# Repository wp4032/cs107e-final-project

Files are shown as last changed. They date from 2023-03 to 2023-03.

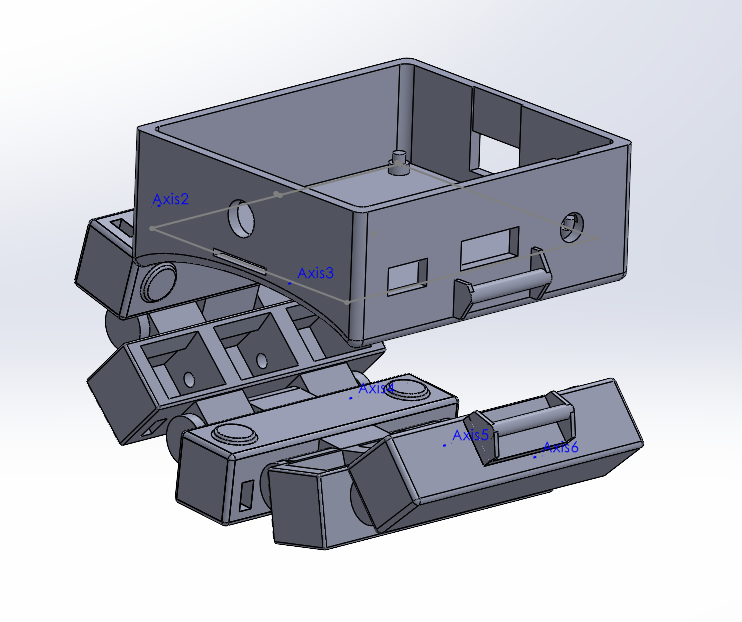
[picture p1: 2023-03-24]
doc/F - PI CAD 1.png

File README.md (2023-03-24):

## Project title
DREAMS DON'T DIE -- MOONWALKER
An EMG-based Brain Machine Interface to Control The World

## Team members
Willian Pan

## Project description
Our nerves communicate with all of our body through send electrical and chemical signals through neurons to the 
desired muscle. It is possible to read these signals from putting electrodes on the skin to detect when certain muscles
fire and relax. Here at DREAMS DON'T DIE Inc., we have designed a wristband that detects these electrical muscle signals
to determine when we have activated a muscle in our hand. As well, using an accelerometer, we can determine the position
of our hand in order to interact with the digital world through this wristband. The project is to build this device and have
it integrate with drawing on the screen like a simple Paint program.

## Instructions
To start the program, run `make` in terminal and then copy the `moonwalker.bin` file to the Raspberry Pi memory card and rename the file
to `kernel.img` while keeping the `bootcode.bin` and `start.elf`. 

Connect a USB A connection the Pi to power the device and also an HDMI cable to output the screen on any desired screen

## Member contribution
William built and designed the physical mechanical parts, circuitry, and software of the device

## References
This project was influenced by CTRL Labs, a company acquired by Meta, that is a wristband with EMG sensors used to interface 
in virtual reality. The device can differentiate when someone uses their fingers in VR, allowing better interaction with virtual 
reality.

The following project also cited several algorithms found online (they are also sprinkled throughout the source code in comments):
- Device Patent: https://patentimages.storage.googleapis.com/3c/5a/7b/39b871805f7eaa/US11045137.pdf
- EMG Circuit: https://www.instructables.com/Muscle-EMG-Sensor-for-a-Microcontroller/
- Tracking arm using accelerometer: https://synrg.csl.illinois.edu/papers/ArmTrak_Mobisys.pdf
- Accelerometer and gyroscope sensor fusion: https://github.com/seanboe/SimpleFusion/blob/master/src/simpleFusion.cpp
- Accelerometer, I2C, LSM6DS33: from CS 107E
- Square root function: https://www.codeproject.com/Articles/570700/SquareplusRootplusalgorithmplusforplusC
- Xiaolin Wu's line drawing algorithm: https://en.wikipedia.org/wiki/Xiaolin_Wu%27s_line_algorithm
- Bresenham circle drawing algorithm: https://www.gatevidyalay.com/bresenham-circle-drawing-algorithm/
- Circle drawing octant: https://www.cs.helsinki.fi/group/goa/mallinnus/ympyrat/ymp1.html

## Self-evaluation
I say that I am pretty proud of building something from the mechanical parts to the electrical parts to the software. It really broadens
my horizons of what full stack means and why hardware is hard. I was able to execute on half of my plan as I was able to get a commercial EMG circuit
board from AdvancerLabs working on Thursday March 23 afternoon, but broke it while soldering. My homemade circuit seemed to work on the oscilloscope, but 
when interfacing with the MCP3008 ADC, it seemed to not produce anything really substatantial. Even though there was this hiccup, I was still proud 
that I was able to get over that barrier and still complete something I am proud of. From this project, I realized why I am a builder and want to be a 
builder for the rest of my life.

## Photos
See doc directory

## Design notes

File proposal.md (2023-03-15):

## CS 107E - Final Project: EMG Brain Machine Interface 

## William Pan

## Project description
I hope to *(1)* create a way for the Raspberry Pi to read neural signals from the forearm through electromyography and *(2)* interface the device with some kind of visual output (LEDs, screen, etc). The final end goal is to create a wristband that reads electrical signals from the muscle when someone closes their hand and opens their hand. As well, I hope to use an accelerometer to detect the rotation of the arm as another way to interact with the device. The output of the device will be a way to interact with a screen i.e. drawing or turning on certain lights. At the end, I hope to learn more about building and designing a device that can be interfaced with humans as well as the electrical engineering aspects of building the device. 

## Hardware, budget
  - 3x TL072 IC Chip 
	- 1x INA106 IC Chip ($13.44)
	- 3x AgCl dry EMG electrodes
	- Alligator clips / wires
	- 2x 9 V batteries
	- 2x 1.0 uF Tant
	- 1x 0.01 uF Ceramic Disc
	- 1x 1.0 uF Ceramic Disc
	- 3x 150 kOhm resistor
	- 2x 1 MOhm resistor
	- 2x 80.6 kOhm resistor
	- 6x 10kOhm resistor
	- 1x 100 kOhm trimmer
	- 1 kOhm resistor
	- 2x 1N4148 Diode
	- 1x breadboard
	- 1x LSM6DS33 3D Accelerometer and Gyro Carrier with Voltage Regulator ($14.95)
	- 2x MCP3008

## Tasks, member responsibilities
  - *William Pan:* building the neural interface device, building the circuit, testing the device, building an interface to control the device

## Schedule, midpoint milestones
  - March 12: Finish building EMG wristband 
  - March 15: Finish code for reading signals from accelerometer and EMG
  - March 19: Refine signals from device
  - March 22: Have device interface with some output (drawing on screen, showing lights, etc.)
  - March 24: Final Project!

## Resources needed, issues
  - Resources:
    - EMG Audio Amplifier: https://www.instructables.com/Build-a-Muscle-Audio-Amplifier-Electromyography/
    - EMG MIDI Music: https://www.instructables.com/Make-Muscle-MIDI-Music/
    - EMG Sensor: https://www.instructables.com/Muscle-EMG-Sensor-for-a-Microcontroller/
    - CTRL Labs Patent: https://patentimages.storage.googleapis.com/3c/5a/7b/39b871805f7eaa/US11045137.pdf
  - Risks
    - Not sure if it will work and does seem ambitious, but driven to make this project work

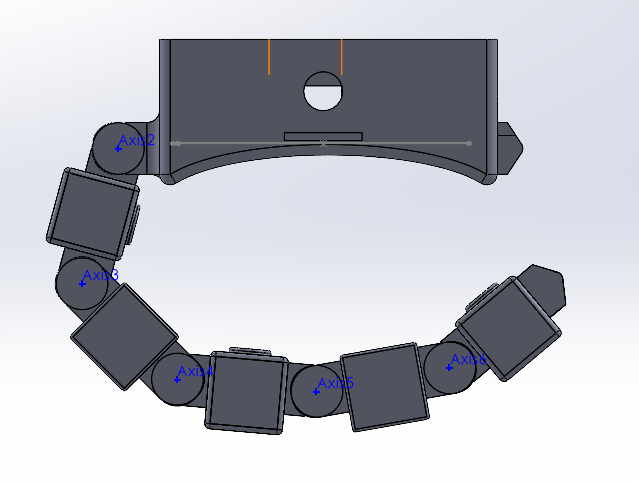
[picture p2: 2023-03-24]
doc/F - PI CAD 2.png

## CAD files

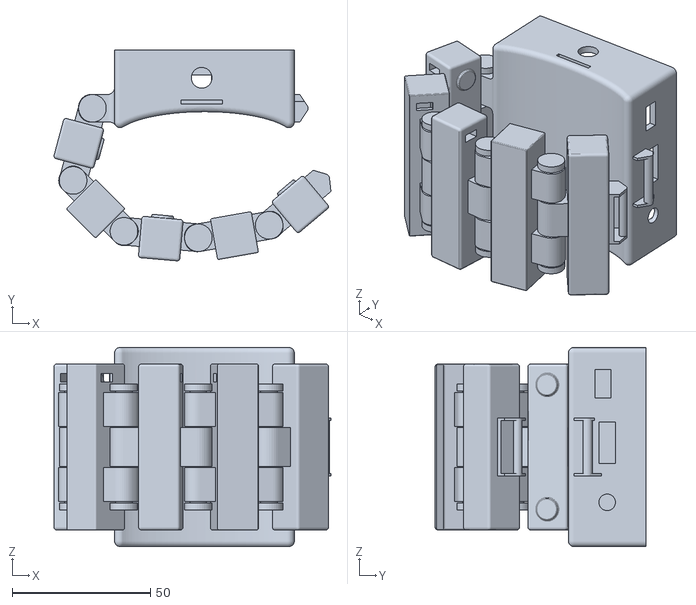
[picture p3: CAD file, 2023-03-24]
doc/F - PI CAD 4.STL
100.2 x 76.2 x 72.0

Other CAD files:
doc/F - PI CAD 3.SLDPRT

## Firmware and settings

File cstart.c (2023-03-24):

#include "uart.h"
#include "malloc.h"
#include "gpio.h"
#include "timer.h"

// linker memmap places these symbols at start/end of bss
extern char __bss_start__, __bss_end__;

extern void main(void);

// Addition added for mini-Valgrind memory report from assignment 4
// void memory_report (void);

// The C function _cstart is called from the assembly in start.s
// _cstart zeroes out the BSS section and then calls main.
// After return from main(), turns on the green ACT LED as
// a sign of successful completion.
void _cstart(void)
{
    char *bss = &__bss_start__;
    char *bss_end = &__bss_end__;

    while (bss < bss_end) {
        *bss++ = 0;
    }

    // Turn on the green ACT LED (GPIO 47), success LED (GPIO 12), and
    gpio_set_output(GPIO_PIN47);
    gpio_set_output(GPIO_PIN12);
    gpio_set_output(GPIO_PIN6);

    gpio_write(GPIO_PIN47, 1);
    gpio_write(GPIO_PIN12, 1);
    gpio_write(GPIO_PIN6, 1);

    timer_delay_ms(250);

    gpio_write(GPIO_PIN6, 0);

    main();

    uart_putchar(EOT);
}

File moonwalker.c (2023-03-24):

#include "timer.h"
#include "uart.h"
#include "accel.h"
#include "i2c.h"
#include "printf.h"
#include "messages.h"
#include "controls.h"
#include "gpio.h"
#include "peripherals.h"
#include "screen.h"
#include "math.h"
#include "interrupts.h"
#include "title.h"

void main(void) 
{
    interrupts_init();
    uart_init();
    timer_init();
    i2c_init();
    accel_init();
    gpio_init();
    peripherals_init();
    math_init();

    // Enables interrupts
    interrupts_global_enable();

    // Initializes the screen
    screen_init();

    // Draws the title screen
    draw_title();

    // Initializes the device and then loops to drraw
    controls_init();
    screen_loop();

    uart_putchar(EOT);
}

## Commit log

2023-03-15 Added accelerometer and LSM6DS33 modules
2023-03-18 Added LEDs and calibration
2023-03-21 accel.c v2 added complementary filter
2023-03-22 accel.c v3 fixed pitch and roll angles
    [test_myprogram.c]
2023-03-22 controls.c v3 with pitch
2023-03-23 Calibration sequence working
2023-03-24 accel.c armtimer interrupts working
2023-03-24 controls.c armtimer interrupts working
2023-03-24 Calibration working
2023-03-24 Final submit
    [F - PI CAD 3.SLDPRT, F - PI CAD 4.STL]
